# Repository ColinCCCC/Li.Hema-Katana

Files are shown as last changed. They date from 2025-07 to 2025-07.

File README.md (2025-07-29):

# 兵击打刀『离』

## 声明

本项目遵循[MIT协议](https://mitsloan.mit.edu/licensing)，允许自由使用、复制、修改、合并、发布、分发和商业化。

不保障项目绝对安全，使用本项目请自负一切后果。

本项目为减伤体育用品设计，请勿用于违反法律法规用途。

制作成品**无需用到任何工业设计专业知识**，如有兴趣，可跟随[下方教程](https://github.com/ColinCCCC/Li.Hema-Katana?tab=readme-ov-file#%E6%88%90%E5%93%81%E5%88%B6%E4%BD%9C)进行制作。

## 成品数据

本项目为用于兵击对练的打刀钢刀设计，使用3mm金属板切件作为刀条，4mm金属板切件作为刀镡。

刀身无渐薄，项目通过直接设计刀身形状，以符合真刀质量分布，并达成减伤要求。

分为轻款与重款，轻重两款共用同一刀柄、刀镡设计，仅刀条存在差异。

### 轻款



- 全长98cm，柄长28cm。采用70%petg打印剑柄并打磨装配后，总重约620g，重心位于镡前约8.5cm。

- 经测试，若选用3mm65Mn或60Si2Mn板材，剑条刺弯压力约9.5kg。

- 数据可能存在浮动，视选材与工艺而定。

### 重款



- 全长105cm，柄长28cm。采用70%petg打印剑柄并打磨装配后，总重约820g，重心位于镡前约10.5cm。

- 经测试，若选用3mm65Mn或60Si2Mn板材，剑条刺弯压力约12kg。

- 数据可能存在浮动，视选材与工艺而定。

## 使用教程

### 成品制作

#### 刀条、刀镡切割

在淘宝等电商应用，搜索并查找提供**65Mn板材激光切割定制**服务的商家，按需选择合适的商品页面，并联系客服。

为商家提供所需的**DXF文件**，按需求说明**每个文件的切割的数量与厚度**，待商家报价后，支付并提供收货地址，即可等待切割成品送达。

*所需DXF文件及其对应厚度如下：*

- 刀条（轻款）【3mm】：[blade-light.DXF](https://github.com/ColinCCCC/Li.Hema-Katana/blob/main/blade-light.DXF)

- 刀条（重款）【3mm】：[blade-heavy.DXF](https://github.com/ColinCCCC/Li.Hema-Katana/blob/main/blade-heavy.DXF)

- 刀镡【4mm】：[hgrd.DXF](https://github.com/ColinCCCC/Li.Hema-Katana/blob/main/hgrd.DXF)

#### 手柄打印

若自备3D打印机，可以自行下载项目中的**STL文件**进行切片打印。

若无3D打印机，可在闲鱼搜索附近提供3D打印服务的商户，提供项目中的**STL文件**，打印后取货。

*所需STL文件及其对应厚度如下：*

- 刀柄（左片）：[hilt-l.STL](https://github.com/ColinCCCC/Li.Hema-Katana/blob/main/hilt-l.STL)

- 刀柄（右片）：[hilt-l.STL](https://github.com/ColinCCCC/Li.Hema-Katana/blob/main/hilt-r.STL)

#### 圆角与抛光

为保障对练安全性，**请务必对刀条进行圆角处理**。若希望追求美观性，可进一步对刀条与刀镡表面进行抛光。

圆角与抛光需要用到砂带机或角磨机，可以选择自行打磨，或就近寻找五金店，请工作人员协助打磨。

### 设计修改

项目使用SOLIDWORKS2025进行设计，项目已附带所有原工程文件。

*所有SLDPRT文件如下：*

- 刀条（轻款）：[blade-light.SLDPRT](https://github.com/ColinCCCC/Li.Hema-Katana/blob/main/blade-light.SLDPRT)

- 刀条（重款）：[blade-heavy.SLDPRT](https://github.com/ColinCCCC/Li.Hema-Katana/blob/main/blade-heavy.SLDPRT)

- 刀柄（左片）：[hilt-l.SLDPRT](https://github.com/ColinCCCC/Li.Hema-Katana/blob/main/hilt-l.SLDPRT)

- 刀柄（右片）：[hilt-l.SLDPRT](https://github.com/ColinCCCC/Li.Hema-Katana/blob/main/hilt-r.SLDPRT)

- 刀镡：[hgrd.SLDPRT](https://github.com/ColinCCCC/Li.Hema-Katana/blob/main/hgrd.SLDPRT)

使用者可以在此基础上，按需求进行修改或再创作。

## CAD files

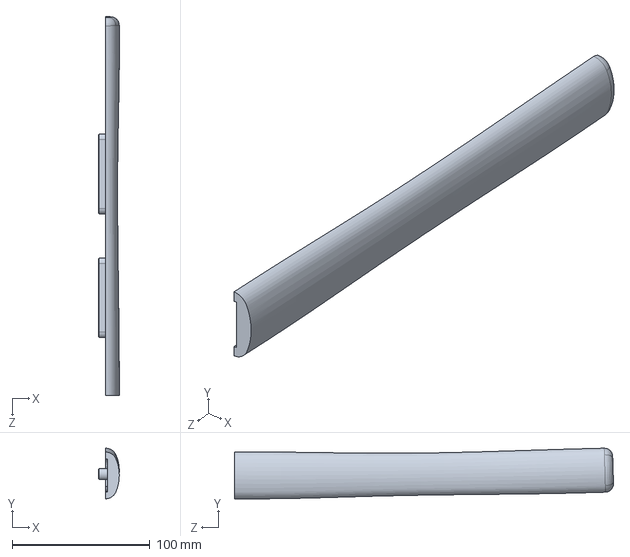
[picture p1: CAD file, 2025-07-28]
hilt-l.SLDPRT
15.0 x 36.8 x 275.3 mm

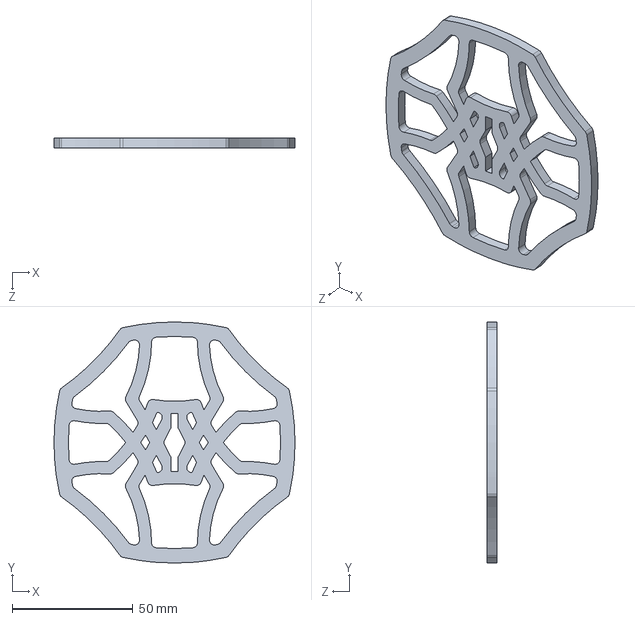
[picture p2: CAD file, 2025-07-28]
hgrd.SLDPRT
100.0 x 100.0 x 4.00 mm

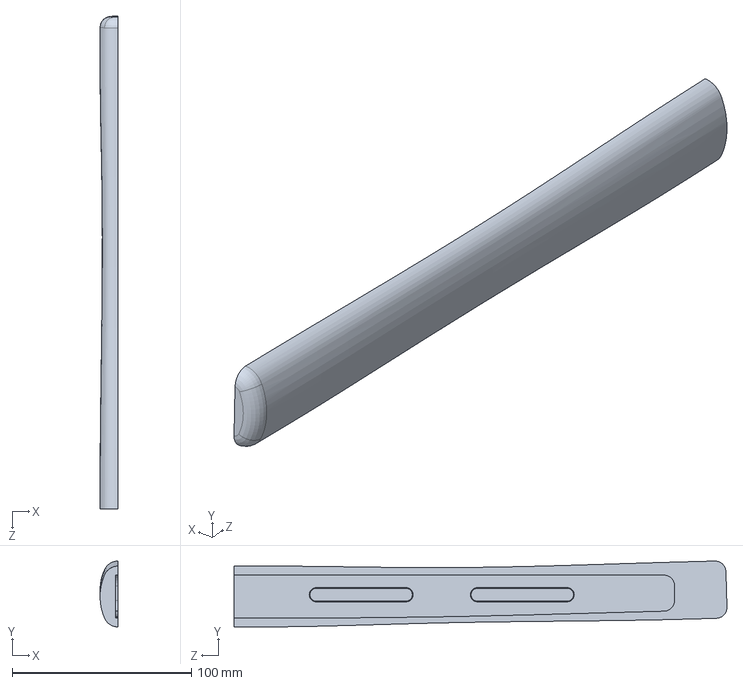
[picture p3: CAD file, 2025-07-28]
hilt-r.SLDPRT
10.0 x 36.8 x 275.3 mm

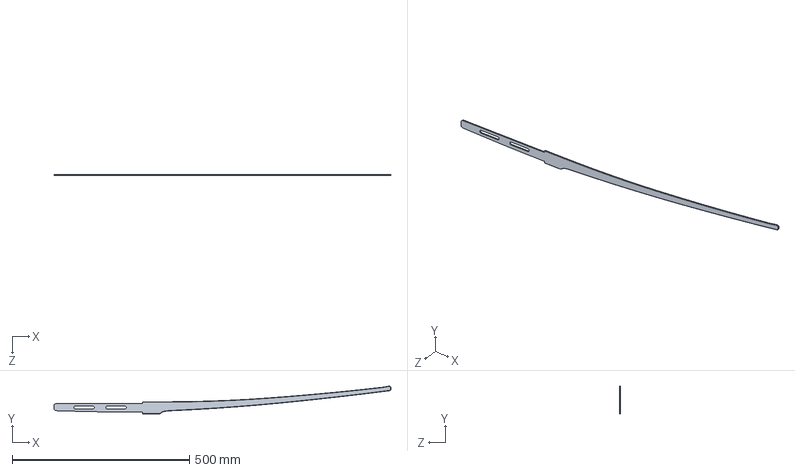
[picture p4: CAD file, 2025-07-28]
blade-light.SLDPRT
950.0 x 78.2 x 3.00 mm

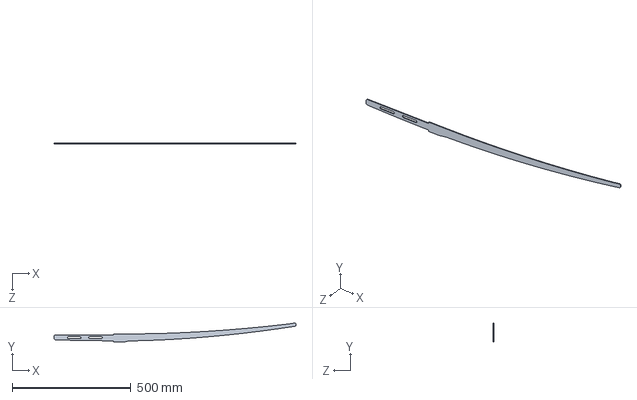
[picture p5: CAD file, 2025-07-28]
blade-heavy.SLDPRT
1020.0 x 79.7 x 3.00 mm

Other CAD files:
blade-heavy.DXF
blade-light.DXF
hgrd.DXF
hilt-l.STL
hilt-r.STL
